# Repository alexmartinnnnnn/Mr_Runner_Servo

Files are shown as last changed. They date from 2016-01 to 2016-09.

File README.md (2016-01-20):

# Mr_Runner_Servo

These are two programs which can be used in conjunction to control the Mr. Runner quadrupedal robot.

The code could be modified to control other 8 jointed robots. The required electronics are a
computer, microcontroller, PCB to power servos, and a serial connection.

https://hackaday.io/project/8843-mr-runner

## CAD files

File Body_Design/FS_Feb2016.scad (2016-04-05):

//horizontal horn holes have been moved out 0.25 mm each (Mar 25)


$fn=64;
difference(){
translate([17.7,-13.1,0])
  cube([6,5,4]);
translate([20.5,-11.1,-1])
    cylinder(6,d=2,d=2);
}
difference(){  
  //main body
  hull(){  
    cylinder(4,d=24,d=24);
    translate([65,0,0])
      cylinder(4,d=24,d=24);
  }
  //spline hole
  translate([0,0,-1])
    cylinder(6,d=8.5,d=8.5);
  //4 horn holes
  translate([0,8.6,-1])
    cylinder(6,d=2.5,d=2.5);
  translate([0,-8.6,-1])
    cylinder(6,d=2.5,d=2.5);
  translate([7.1,0,-1])
    cylinder(6,d=2.5,d=2.5);
  translate([-7.1,0,-1])
    cylinder(6,d=2.5,d=2.5);
  //spring hole
  translate([20.5,-11.1,-1])
    cylinder(6,d=2,d=2);
  //main servo hole
  translate([24.5,-10,-1])
    cube([41,20,6]);
  //servo top slit
  translate([18.5,-1,-1])
    cube([6.5,2,6]);
  //top servo screws
  translate([21,5,-1])
    cylinder(6,d=3.5,d=3.5);
  translate([21,-5,-1])
    cylinder(6,d=3.5,d=3.5);
  //servo bottom slit
  translate([65,-1,-1])
    cube([6.5,2,6]);
  //bottom servo screws
  translate([69,5,-1])
    cylinder(6,d=3.5,d=3.5);
  translate([69,-5,-1])
    cylinder(6,d=3.5,d=3.5);
  //contours
  //horn side
  difference(){
    translate([7,11,-1])
      rotate([0,0,180])
        scale([1,0.8,1])
          cylinder(6,d=20,d=20,$fn=3);
    cylinder(6,d=24,d=24); 
  }
  difference(){
    translate([7,-11,-1])
      rotate([0,0,-180])
        scale([1,0.8,1])
          cylinder(6,d=20,d=20,$fn=3);
    cylinder(6,d=24,d=24); 
  }
  //body side 
  mirror([-1,0,0]){
  translate([-23.95,0,-1])  
    difference(){
      translate([7,-11,0])
        rotate([0,0,180])
          scale([1,0.8,1])
            cylinder(6,d=20,d=20,$fn=3);
      cylinder(6,d=24,d=24); 
    }
  }
  mirror([0,-1,0]){
  mirror([-1,0,0]){
  translate([-23.95,0,-1])  
    difference(){
      translate([7,-11,0])
        rotate([0,0,180])
          scale([1,0.8,1])
            cylinder(6,d=20,d=20,$fn=3);
      cylinder(6,d=24,d=24); 
    }
  }
}
}

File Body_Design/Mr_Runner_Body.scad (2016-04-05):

//ALL SERVO HOLE WIDTHS ARE APPROPRIATE. ADJUST SERVO MOUNTS FOR PROPER CLEARANCE

//ROUND EXTENSION BOTTOM FRONT CORNERS

$fn=64;

//front extension
difference(){
translate([172,-25,0])     cube([59,25,5]);
    
translate([168,-26,3]) rotate([0,45,0])     cube([4,26,8]); 
}
  
//back extension
difference(){
translate([172,95,0])     cube([59,25,5]);
    
translate([168,95,3])  rotate([0,45,0])     cube([4,26,8]); 
}
//main body
difference(){
translate([-1,0,0])      cube([232,95,5]);  
    
translate([152,15,-2.5])    cube([7,63,10]);
    
translate([-5,-1,3])    rotate([0,45,0])     cube([4,97,8]); 
}

//front hip servo mounts
difference(){
translate([172,-25,-19.8]) cube([10,8,19.8]);
    
translate([177.3,-10,-4.9])rotate([90,0,0]) cylinder(20,1.8,1.8);
    
translate([177.3,-10,-14.9])rotate([90,0,0]) cylinder(20,1.8,1.8);
}

difference(){
translate([221,-25,-19.8]) cube([10,8,19.8]);

translate([225.7,-10,-4.9])rotate([90,0,0]) cylinder(20,1.8,1.8);
    
translate([225.7,-10,-14.9])rotate([90,0,0]) cylinder(20,1.8,1.8);
}

//rear hip servo mounts
difference(){
translate([172,112,-19.8]) cube([10,8,19.8]);
    
translate([177.3,128,-4.9])rotate([90,0,0]) cylinder(20,1.8,1.8);
    
translate([177.3,123,-14.9])rotate([90,0,0]) cylinder(20,1.8,1.8);
}

difference(){
translate([221,112,-19.8]) cube([10,8,19.8]);

translate([225.7,123,-4.9])rotate([90,0,0]) cylinder(20,1.8,1.8);
    
translate([225.7,120,-14.9])rotate([90,0,0]) cylinder(20,1.8,1.8);
}

//front shoulder servo mounts
difference(){
translate([-1,0,-19.8])   cube([10,8,19.8]);
    
translate([4.6,17,-4.9])  rotate([90,0,0]) cylinder(20,1.8,1.8);
    
translate([4.6,17,-14.9]) rotate([90,0,0]) cylinder(20,1.8,1.8);
}

difference(){
translate([48.6,0,-19.8])   cube([10,8,19.8]);
    
translate([53,17,-4.9])  rotate([90,0,0]) cylinder(20,1.8,1.8);
    
translate([53,17,-14.9]) rotate([90,0,0]) cylinder(20,1.8,1.8);
}

//rear shoulder servo mount
difference(){
translate([-1,87,-19.8])   cube([10,8,19.8]);
    
translate([4.6,97,-4.9])  rotate([90,0,0]) cylinder(20,1.8,1.8);
    
translate([4.6,97,-14.9]) rotate([90,0,0]) cylinder(20,1.8,1.8);
}

difference(){
translate([48.6,87,-19.8])   cube([10,8,19.8]);
    
translate([53,98,-4.9])  rotate([90,0,0]) cylinder(20,1.8,1.8);
    
translate([53,98,-14.9]) rotate([90,0,0]) cylinder(20,1.8,1.8);
}

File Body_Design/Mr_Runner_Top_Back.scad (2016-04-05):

//servo mounts have been moved down 1mm and each 0.5 mm further from each other

$fn=64;

//front extension
difference(){
translate([-1.5,-25,0])     cube([60,25,5]);
    
translate([-5,-26,3])  rotate([0,45,0])     cube([4,26,8]); 
}
  
//back extension
difference(){
translate([-1.5,95,0])     cube([60,25,5]);
    
translate([-5,95,3])   rotate([0,45,0])     cube([4,26,8]); 
}
//main body
difference(){
translate([-1.5,0,0])      cube([60,95,5]);  
    
translate([-5,-1,3])    rotate([0,45,0])     cube([4,97,8]); 
}

//front hip servo mounts
difference(){
translate([-1.5,-17,-19.8]) cube([10,8,20.8]);
    
translate([4.3,-2,-4.9])rotate([90,0,0]) cylinder(20,1.8,1.8);
    
translate([4.3,-2,-14.9])rotate([90,0,0]) cylinder(20,1.8,1.8);
}

difference(){
translate([48.5,-17,-19.8]) cube([10,8,20.8]);

translate([52.7,-2,-4.9])rotate([90,0,0]) cylinder(20,1.8,1.8);
    
translate([52.7,-2,-14.9])rotate([90,0,0]) cylinder(20,1.8,1.8);
}

//rear hip servo mounts
difference(){
translate([-1.5,104,-19.8]) cube([10,8,20.8]);
    
translate([4.3,120,-4.9])rotate([90,0,0]) cylinder(20,1.8,1.8);
    
translate([4.3,115,-14.9])rotate([90,0,0]) cylinder(20,1.8,1.8);
}

difference(){
translate([48.5,104,-19.8]) cube([10,8,20.8]);

translate([52.7,115,-4.9])rotate([90,0,0]) cylinder(20,1.8,1.8);
    
translate([52.7,115,-14.9])rotate([90,0,0]) cylinder(20,1.8,1.8);
}

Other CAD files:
Body_Design/Mr_Runner_Top_Front.scad
Body_Design/SS_Feb2016.scad
Body_Design/TS2_Feb2016.scad
Body_Design/TS_Feb2016.scad

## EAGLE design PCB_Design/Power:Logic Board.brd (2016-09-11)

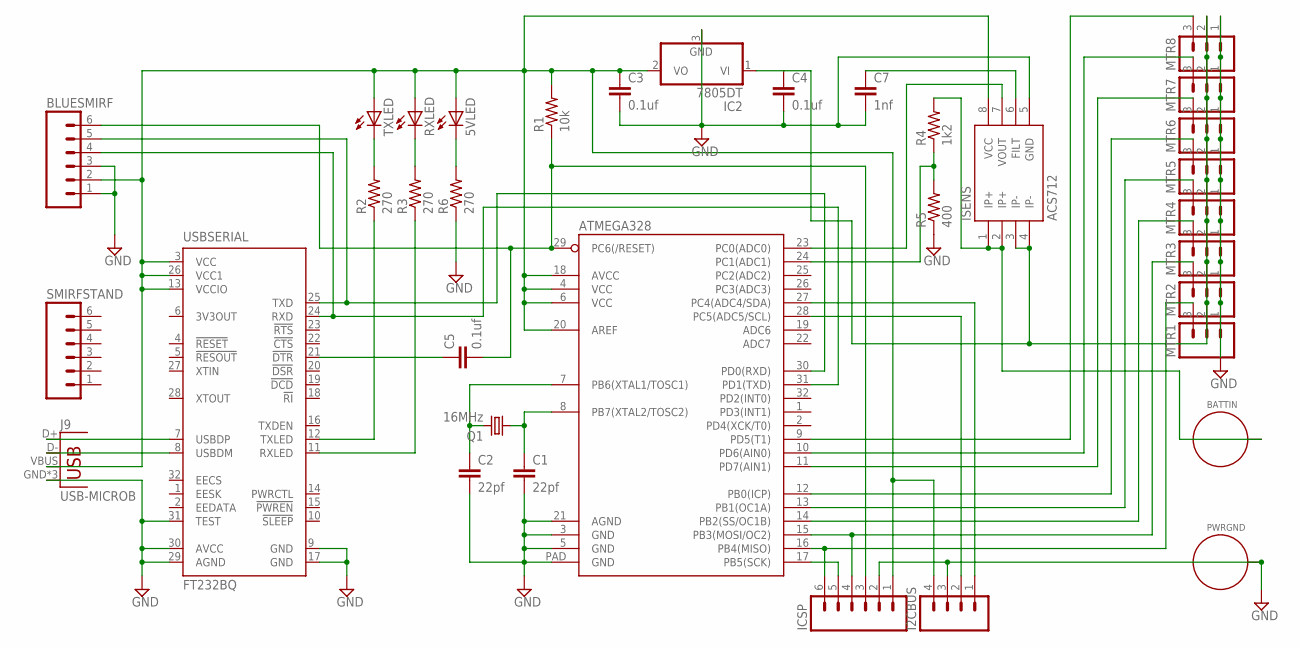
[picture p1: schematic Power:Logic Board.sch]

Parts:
5VLED: LEDCHIPLED_0805; CHIPLED_0805
ATMEGA328: ATMEGA328P_MLFMLF32; MLF32-PAD
BATTIN: STANDOFF_ELECTRICAL; STANDOFF-ELECTRICAL
BLUESMIRF: M06NO_SILK_YES_STOP; 1X06_NO_SILK_YES_STOP
C1, C2: 22pf; C0805
C3, C4, C5: 0.1uf; C0805
C7: 1nf; C0805
I2CBUS: M04NO_SILK_ALL_ROUND; 1X04_NO_SILK_ALL_ROUND
IC2: 7805DT; TO252
ICSP: M06NO_SILK_YES_STOP; 1X06_NO_SILK_YES_STOP
ISENS: ACS712; SO08
J9: USB-MICROB
MTR1, MTR2, MTR3, MTR4, MTR5, MTR6, MTR7, MTR8: M03PTH; 1X03
PWRGND: STANDOFF_ELECTRICAL; STANDOFF-ELECTRICAL
Q1: 16MHz; HC49U-V
R1: 10k; 0805
R2, R3, R6: 270; 0805
R4: 1k2; 0805
R5: 400; 0805
RXLED: LEDCHIPLED_0805; CHIPLED_0805
SMIRFSTAND: M06NO_SILK_YES_STOP; 1X06_NO_SILK_YES_STOP
TXLED: LEDCHIPLED_0805; CHIPLED_0805
USBSERIAL: FT232BQ; QFN32

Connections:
GND: ATMEGA328.3 (GND), ATMEGA328.5 (GND), ATMEGA328.21 (AGND), ATMEGA328.PAD (GND), BLUESMIRF.1, BLUESMIRF.3, C1.2, C2.2, C3.2, C4.2, C7.2, I2CBUS.3, IC2.3 (GND), ICSP.2, ISENS.5 (GND), J9.GND, J9.MT1 (GND), J9.MT2 (GND), MTR1.1, MTR2.1, MTR3.1, MTR4.1, MTR5.1, MTR6.1, MTR7.1, MTR8.1, PWRGND.P1, R5.1, R6.1, USBSERIAL.9 (GND), USBSERIAL.17 (GND), USBSERIAL.29 (AGND), USBSERIAL.30 (AVCC), USBSERIAL.31 (TEST)
unnamed: J9.D+, USBSERIAL.7 (USBDP)
unnamed: ATMEGA328.31 (PD1(TXD)), BLUESMIRF.4, USBSERIAL.24 (RXD)
unnamed: J9.D-, USBSERIAL.8 (USBDM)
unnamed: 5VLED.A, ATMEGA328.4 (VCC), ATMEGA328.6 (VCC), ATMEGA328.18 (AVCC), ATMEGA328.20 (AREF), BLUESMIRF.2, C3.1, I2CBUS.4, IC2.2 (VO), ICSP.1, ISENS.8 (VCC), J9.VBUS, R1.2, RXLED.A, TXLED.A, USBSERIAL.3 (VCC), USBSERIAL.13 (VCCIO), USBSERIAL.26 (VCC1)
unnamed: ATMEGA328.14 (PB2(SS/OC1B)), MTR3.3
unnamed: ATMEGA328.23 (PC0(ADC0)), ISENS.7 (VOUT)
unnamed: ATMEGA328.8 (PB7(XTAL2/TOSC2)), C1.1, Q1.1
unnamed: ATMEGA328.9 (PD5(T1)), MTR8.3
unnamed: ATMEGA328.13 (PB1(OC1A)), MTR4.3
unnamed: ATMEGA328.17 (PB5(SCK)), ICSP.5
unnamed: ATMEGA328.12 (PB0(ICP)), MTR5.3
unnamed: ATMEGA328.16 (PB4(MISO)), ICSP.6, MTR1.3
unnamed: ATMEGA328.15 (PB3(MOSI/OC2)), ICSP.4, MTR2.3
unnamed: R2.2, TXLED.C
unnamed: ATMEGA328.7 (PB6(XTAL1/TOSC1)), C2.1, Q1.2
unnamed: R2.1, USBSERIAL.12 (TXLED)
unnamed: R3.2, RXLED.C
unnamed: R3.1, USBSERIAL.11 (RXLED)
unnamed: ATMEGA328.11 (PD7(AIN1)), MTR6.3
unnamed: ATMEGA328.29 (PC6(/RESET)), BLUESMIRF.6, C5.2, ICSP.3, R1.1
unnamed: C7.1, ISENS.6 (FILT)
unnamed: C4.1, IC2.1 (VI), ISENS.3 (IP-), ISENS.4 (IP-), MTR1.2, MTR2.2, MTR3.2, MTR4.2, MTR5.2, MTR6.2, MTR7.2, MTR8.2
unnamed: ATMEGA328.24 (PC1(ADC1)), R4.1, R5.2
unnamed: ATMEGA328.10 (PD6(AIN0)), MTR7.3
unnamed: BATTIN.P1, ISENS.1 (IP+), ISENS.2 (IP+), R4.2
unnamed: ATMEGA328.30 (PD0(RXD)), BLUESMIRF.5, USBSERIAL.25 (TXD)
unnamed: C5.1, USBSERIAL.21 (!DTR)
unnamed: ATMEGA328.28 (PC5(ADC5/SCL)), I2CBUS.2
unnamed: ATMEGA328.27 (PC4(ADC4/SDA)), I2CBUS.1
unnamed: 5VLED.C, R6.2

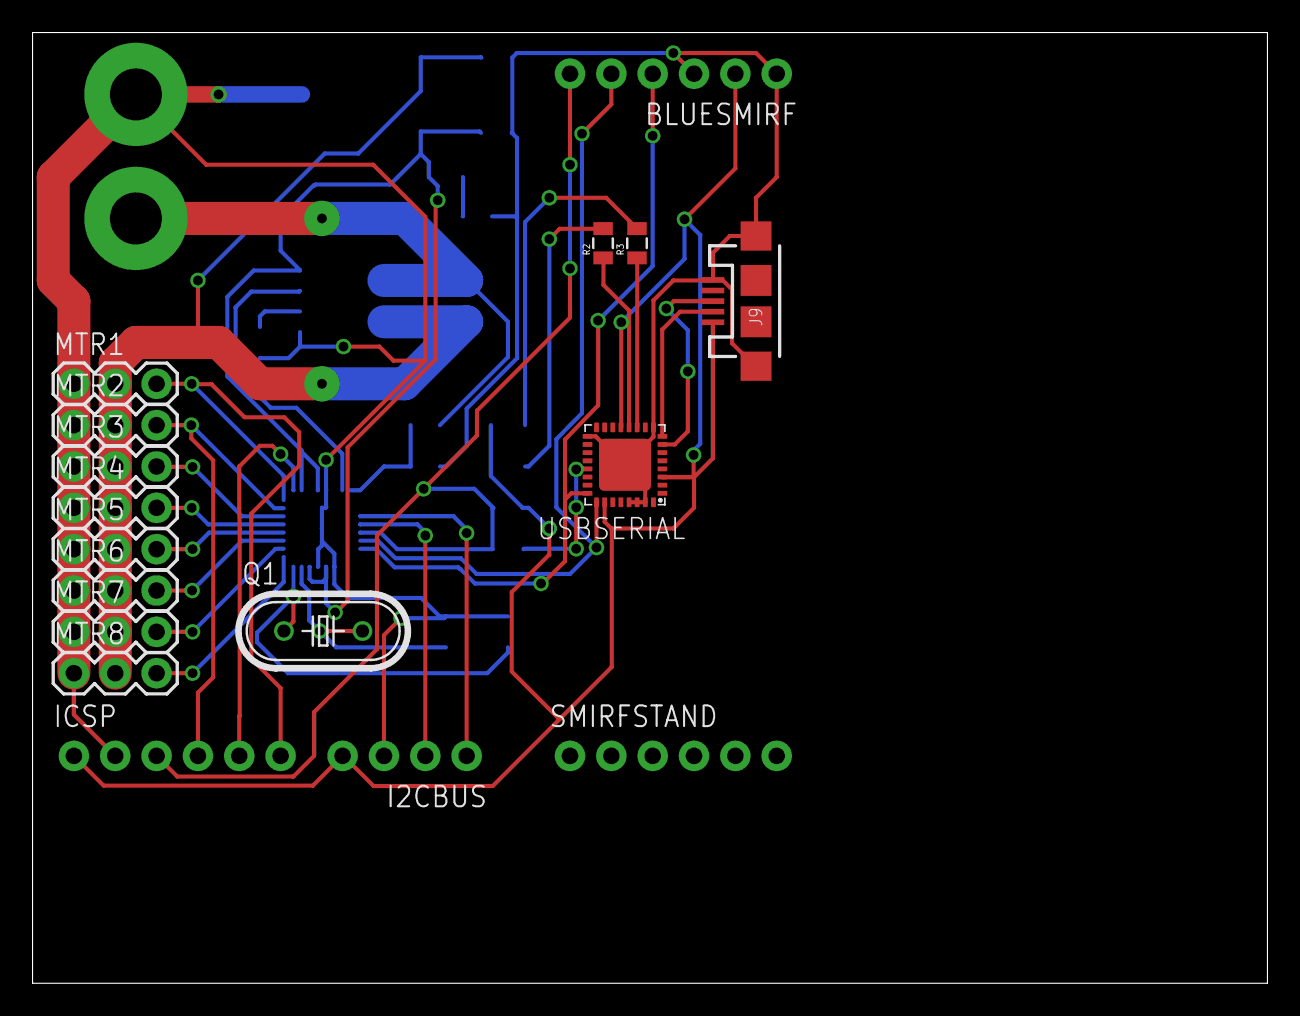
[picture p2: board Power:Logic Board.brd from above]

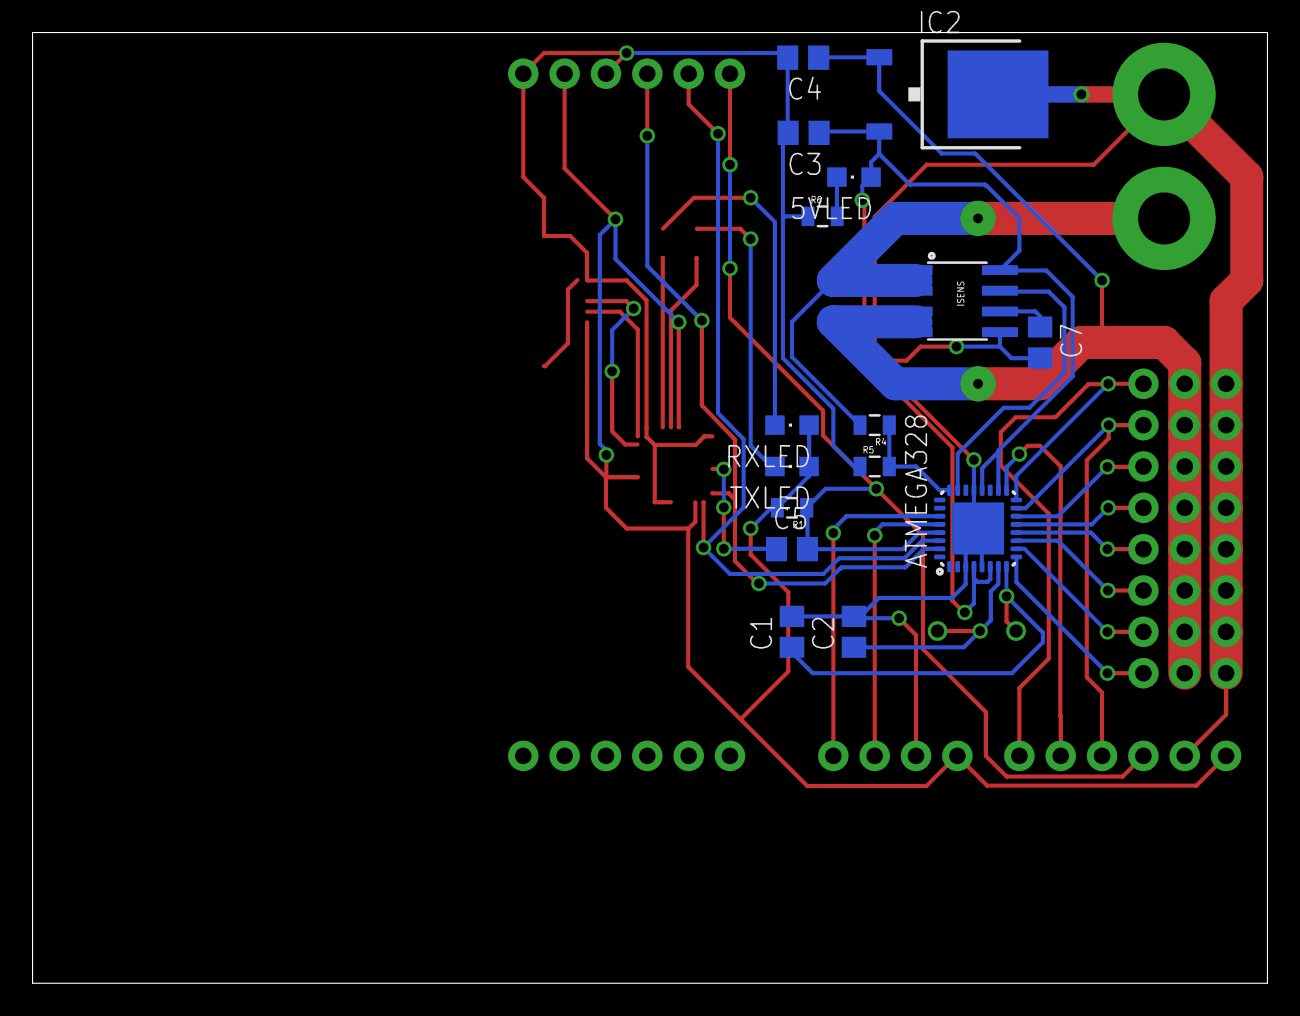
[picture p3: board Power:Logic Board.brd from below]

Board: 2 copper layers, 75.9 x 58.4 mm, 35 parts (16 on the bottom side), 31 nets.

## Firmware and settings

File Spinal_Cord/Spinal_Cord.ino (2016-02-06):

/*
This is a program that recieves sine wave parameters from a serial connection in a single string.
The string is parsed and converted into numbers, which are plugged into 8 sine equations to generate
positions for each joint of the robot.
*/

#include <Servo.h>

Servo SB, SF, HB, HF, EB, EF, KB, KF;
int iAmp, iF_offset, iB_offset, iFk_offset, iBk_offset, pos[] = {0,1,2,3,4,5,6,7};
unsigned int t = 0;
unsigned long previousMillis = 0;
float fKnee_amp, fAfreq, fPhase, fGait;

void setup(){
  //Start serial stream at 115200 baud
  Serial.begin(115200);
  
  //Connect servos to Arduino
  HB.attach(2);
  KF.attach(3);
  SB.attach(4); 
  EB.attach(5);
  HF.attach(6); 
  KB.attach(7);
  SF.attach(8); 
  EF.attach(9);
  
  delay(3000);
}

void loop(){
  char c, buffer[10];
  String readString, amp, knee_amp, afreq, gait, phase, f_offset, b_offset, fk_offset, bk_offset;
  unsigned int sine_time = 0.05;
    
  while (Serial.available() && readString.length() < 37){
    //delay to allow buffer to fill
    delayMicroseconds(100);
    if (Serial.available() > 0){
      //get one byte from serial buffer
      char c = Serial.read();
      //creates the string "readString"
      readString += c;
    }
  }

  if (readString.length() > 36){
    //see what was received
    Serial.println("The string is: " + readString);
    Serial.println(readString.length()); 
    
    //parse serial string into separate parameters
    amp = readString.substring(0, 3);
    knee_amp = readString.substring(3, 7); 
    afreq = readString.substring(7, 11); 
    phase = readString.substring(11, 15); 
    gait = readString.substring(15, 20); 
    f_offset = readString.substring(20, 24); 
    b_offset = readString.substring(24, 28); 
    fk_offset = readString.substring(28, 32); 
    bk_offset = readString.substring(32, 36);
    /*
    //Print to serial monitor to see parsed results
    Serial.println("Hip Amp: " + amp); 
    Serial.println("Knee Amp: " + knee_amp); 
    Serial.println("Afreq: " + afreq); 
    Serial.println("Gait: " + gait);
    Serial.println("Phase: " + phase);
    Serial.println("F Offset: " + f_offset);
    Serial.println("B Offset: " + b_offset);  
    Serial.println("Fk Offset: " + fk_offset);
    Serial.println("Bk Offset: " + bk_offset + "\n");
    */
    //convert string values to numbers
    iAmp = amp.toInt();
  
    knee_amp.toCharArray(buffer, 10);
    fKnee_amp = atof(buffer);
    memset(buffer, 0, sizeof(buffer));
  
    afreq.toCharArray(buffer, 10);
    fAfreq = atof(buffer)/100;
    memset(buffer, 0, sizeof(buffer));
  
    phase.toCharArray(buffer, 10);
    fPhase = atof(buffer);
    memset(buffer, 0, sizeof(buffer));
  
    gait.toCharArray(buffer, 10);
    fGait = atof(buffer);
    memset(buffer, 0, sizeof(buffer));
  
    iF_offset = f_offset.toInt();
    iB_offset = b_offset.toInt();
    iFk_offset = fk_offset.toInt();
    iBk_offset = bk_offset.toInt();
   
    //clear strings
    readString="";
    amp="";
    knee_amp="";
    afreq="";
    gait="";
    phase="";
    f_offset="";
    b_offset="";
    fk_offset="";
    bk_offset="";
  }
  
  //if the joints should be oscillating
  if (fAfreq > 0){
    //determine joint positions
    pos[0] = iAmp * sin(fAfreq*t) + 1500 + iF_offset;
    pos[1] = iAmp * sin(fAfreq*t) + 1522 - iF_offset;
    pos[2] = iAmp * sin(fAfreq*t + fGait) + 1500 + iB_offset;
    pos[3] = iAmp * sin(fAfreq*t + fGait) + 1446 - iB_offset;
 
    pos[4] = iAmp*fKnee_amp * sin(fAfreq*t + fPhase) + 1500 + iFk_offset;
    pos[5] = iAmp*fKnee_amp * sin(fAfreq*t + fPhase) + 1581 - iFk_offset;
    pos[6] = iAmp*fKnee_amp * sin(fAfreq*t + fGait + fPhase) + 1500 + iBk_offset;
    pos[7] = iAmp*fKnee_amp * sin(fAfreq*t + fGait + fPhase) + 1538 - iBk_offset;
    /*
    //print parameter variables
    Serial.println(iAmp); 
    Serial.println(fKnee_amp); 
    Serial.println(fAfreq); 
    Serial.println(fGait);
    Serial.println(fPhase);
    Serial.println(iF_offset);
    Serial.println(iB_offset);  
    Serial.println(iFk_offset);
    Serial.println(iBk_offset);
    
    //print servo positions
    Serial.println(pos[0]);
    Serial.println(pos[1]);
    Serial.println(pos[2]);
    Serial.println(pos[3]);
    Serial.println(pos[4]);
    Serial.println(pos[5]);
    Serial.println(pos[6]);
    Serial.println(pos[7]);
    */
    //get time in milliseconds
    unsigned long currentMillis = millis();
  
    //if the time threshold has been passed
    if(currentMillis - previousMillis >= sine_time){
      previousMillis = currentMillis;
    
      //write servo positions
      HB.writeMicroseconds(pos[2]);
      KF.writeMicroseconds(pos[6]);
      SB.writeMicroseconds(pos[0]); 
      EB.writeMicroseconds(pos[4]);
      HF.writeMicroseconds(pos[3]); 
      KB.writeMicroseconds(pos[7]);
      SF.writeMicroseconds(pos[1]); 
      EF.writeMicroseconds(pos[5]);
    
      //increment time parameter
      t+=1;
    }
  }
}

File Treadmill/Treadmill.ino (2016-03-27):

/* 
Program to control the AD5220 digipot via UART. The pot is initialized at max
resistance then controlled with the '+' and '-' characters.
*/

//control pins on AD5220
int CLK = 8, UD = 9, CS = 10;
//serial byte
char set_speed;
//parameter for counting time
unsigned long previousMillis = 0;
//to measure wiper voltage
float v_wiper;

void setup(){
  //pro mini bootloader communicates at 57600 baud
  Serial.begin(57600);
  
  pinMode(CS, OUTPUT);
  pinMode(UD, OUTPUT);
  pinMode(CLK, OUTPUT);
  
  //change pot wiper from middle to max resistance
  for (int i=0; i<20; i++){
    decrease_speed();
  }
  
  //hold current pot resistance
  digitalWrite(CS, HIGH);
  digitalWrite(CLK, HIGH);
}

void loop(){
  //get current time
  unsigned long currentMillis = millis();
  
  int wiper = analogRead(A0);
  v_wiper = wiper * (3.3 / 1023);
  
  //if 2000 msecs have passed
  if (currentMillis - previousMillis >= 2000){
    previousMillis = currentMillis;
    
    Serial.println(v_wiper);
  }
  
  //read serial data when it arrives
  if (Serial.available() > 0){
    set_speed = Serial.read();
  }
  
  //decrease speed
  if (set_speed == '-'){
    decrease_speed();
  }
  
  //increase speed
  else if (set_speed == '+'){
    increase_speed();
  }
  
  //get belt moving
  else if (set_speed == 's'){
    start();
  }
  
  //stop the belt
  else if (set_speed == 'e'){
    stop();
  }
  
  //hold pot resistance  
  else {
    digitalWrite(CS, HIGH);
  }
}

void decrease_speed(){
  digitalWrite(CS, LOW);
  digitalWrite(UD, LOW);
  digitalWrite(CLK, LOW);
  digitalWrite(CLK, HIGH);
    
  set_speed = '\0';
}

void increase_speed(){
  digitalWrite(CS, LOW);
  digitalWrite(UD, HIGH);
  digitalWrite(CLK, LOW);
  digitalWrite(CLK, HIGH);
    
  set_speed = '\0';
}

//increase wiper voltage to ~0.75V, when belt starts moving
void start(){
  for (int i = 0; i < 30; i++){
    digitalWrite(CS, LOW);
    digitalWrite(UD, HIGH);
    digitalWrite(CLK, LOW);
    digitalWrite(CLK, HIGH);
  }
  set_speed = '\0';
}

void stop(){
  while (v_wiper > 0.5){
    decrease_speed();
  }
}

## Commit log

2016-01-05 Create Brain.py
    Generates servo positions, controls oscillators from a gui, transmits servo positions via serial.
    [Brain.py]
2016-01-05 Create Spinal_Cord.ino
    Receives servo positions from the brain and relays them to the motors.

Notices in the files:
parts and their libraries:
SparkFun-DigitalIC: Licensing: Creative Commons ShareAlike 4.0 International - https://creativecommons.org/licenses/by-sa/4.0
